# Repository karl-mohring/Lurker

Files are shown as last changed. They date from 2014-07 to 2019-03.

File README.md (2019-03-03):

# Lurker
Wireless sensor network for home environmental monitoring. 

# Installation

## Hardware
### Parts List
1 x Arduino Nano
1 x RF24L01+ Transceiver
1 x DS18B20 Temperature sensor
1 x DHT11 Humidity sensor
1 x BH1750FVI Illuminance sensor
1 x HC-SR501 PIR Motion sensor
2 x 4K7 Ohm resistor (1206 SMD)
2 x 390R Ohm resistor (1206 SMD)
2 x 3mm 2~3V LEDs

Optional - These components are still in development
1 x IR Blaster
1 x IR Receiver
1 x Microphone

### Circuit Board
The Lurker uses a custom PCB to connect the sensors and components together. 

### Casing
## Software

# Usage

# Network Heirarchy

# Other Info

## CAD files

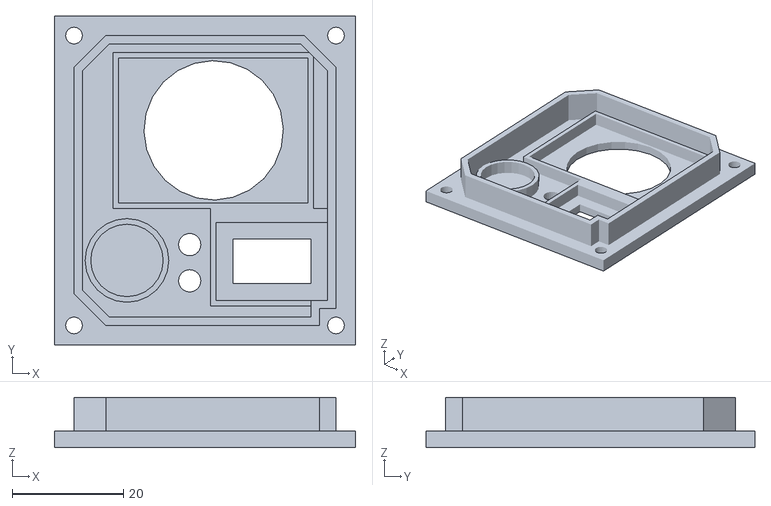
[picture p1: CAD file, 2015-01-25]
CAD/LurkerCase/LurkerLid.stl
54.0 x 59.0 x 9.00

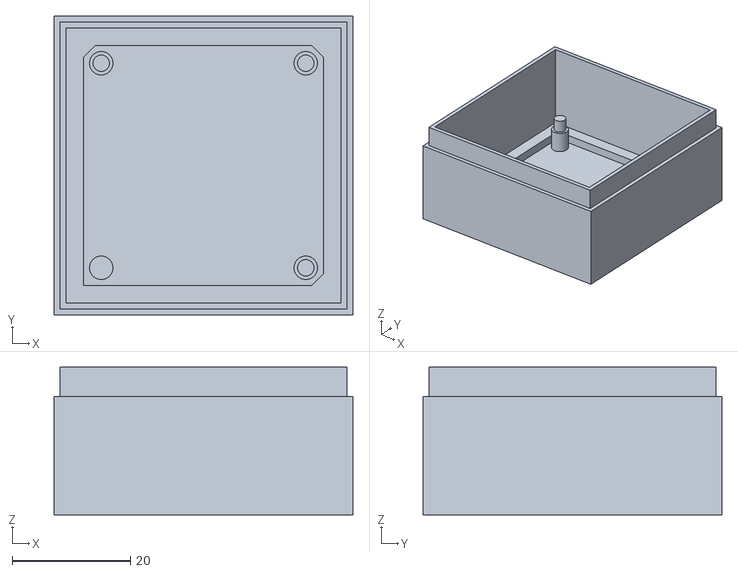
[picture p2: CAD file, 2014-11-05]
CAD/Lurkerv20 Enclosure/Lurkerv20 Baseplate.stl
50.6 x 50.6 x 25.0

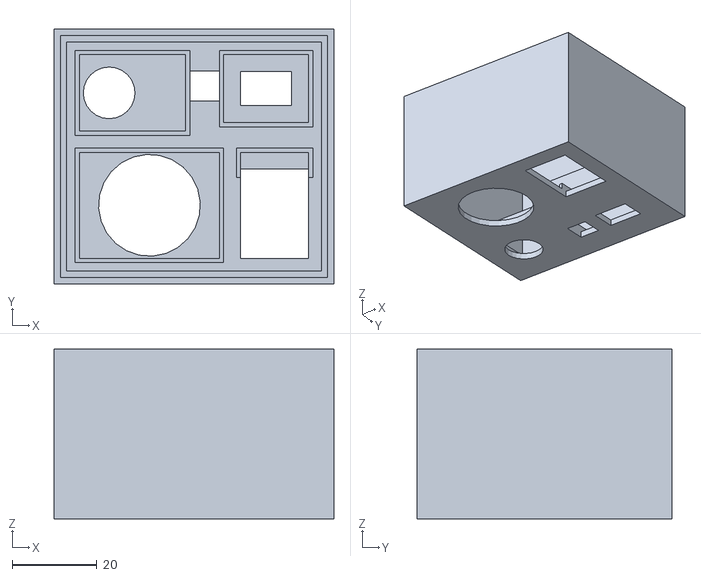
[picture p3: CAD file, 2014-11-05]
CAD/Office Lurker Enclosure/sensor topv1.stl
66.0 x 60.0 x 40.0

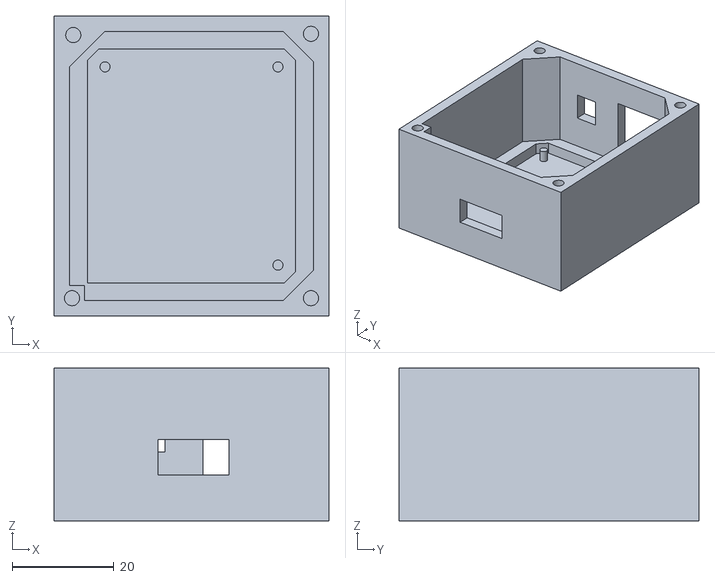
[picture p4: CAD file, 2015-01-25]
CAD/LurkerCase/LurkerCase.stl
54.0 x 59.0 x 30.0

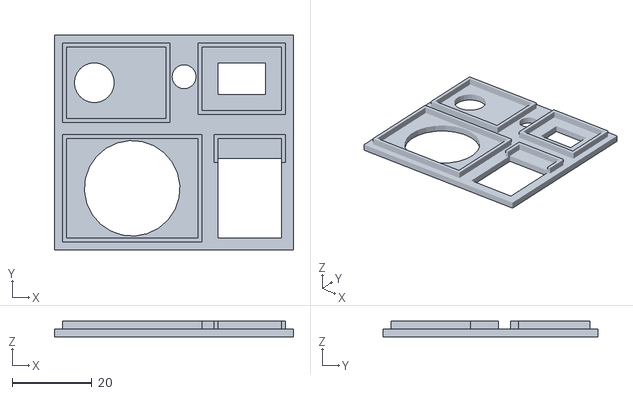
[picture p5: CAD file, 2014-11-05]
CAD/Office Lurker Enclosure/sensor top test_fixed.stl
60.0 x 54.0 x 4.00

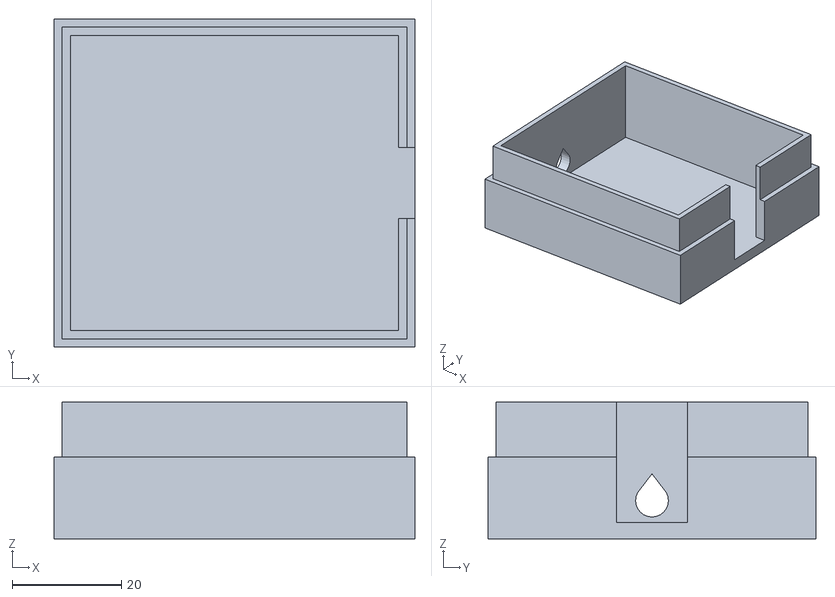
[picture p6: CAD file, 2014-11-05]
CAD/Office Lurker Enclosure/sensor bottom.stl
66.0 x 60.0 x 25.0

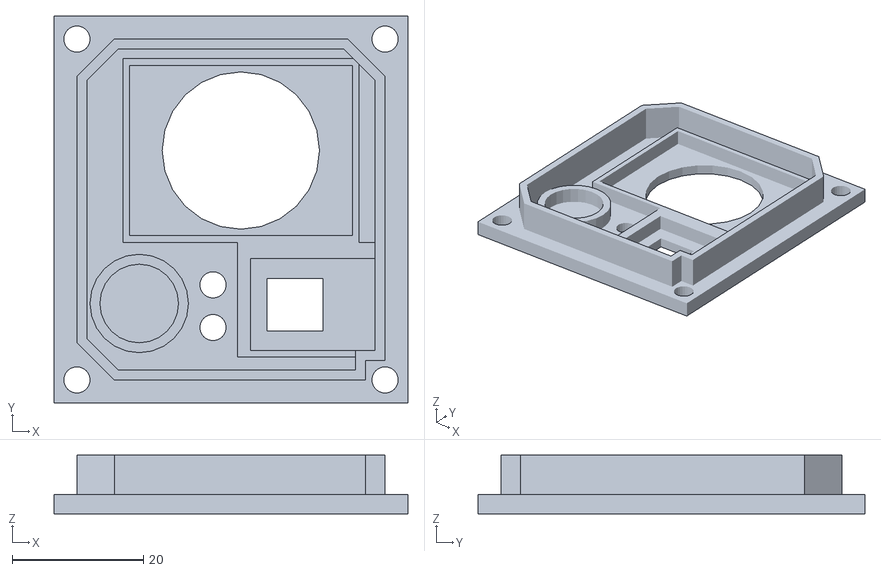
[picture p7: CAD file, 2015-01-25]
CAD/LurkerCase/LurkerLid-v3.stl
54.0 x 59.0 x 9.00

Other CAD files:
CAD/LurkerCase/LurkerCase-v3.stl
CAD/LurkerCase/LurkerCase-v3.skp
CAD/LurkerCase/LurkerCase.skp
CAD/LurkerCase/LurkerLid-v3.skp
CAD/LurkerCase/LurkerLid.skp
CAD/Lurkerv20 Enclosure/Lurkerv20 Baseplate.skp
CAD/Lurkerv20 Enclosure/Lurkerv20 Faceplate.skp
CAD/Office Lurker Enclosure/sensor bottom.skp
CAD/Office Lurker Enclosure/sensor top.skp

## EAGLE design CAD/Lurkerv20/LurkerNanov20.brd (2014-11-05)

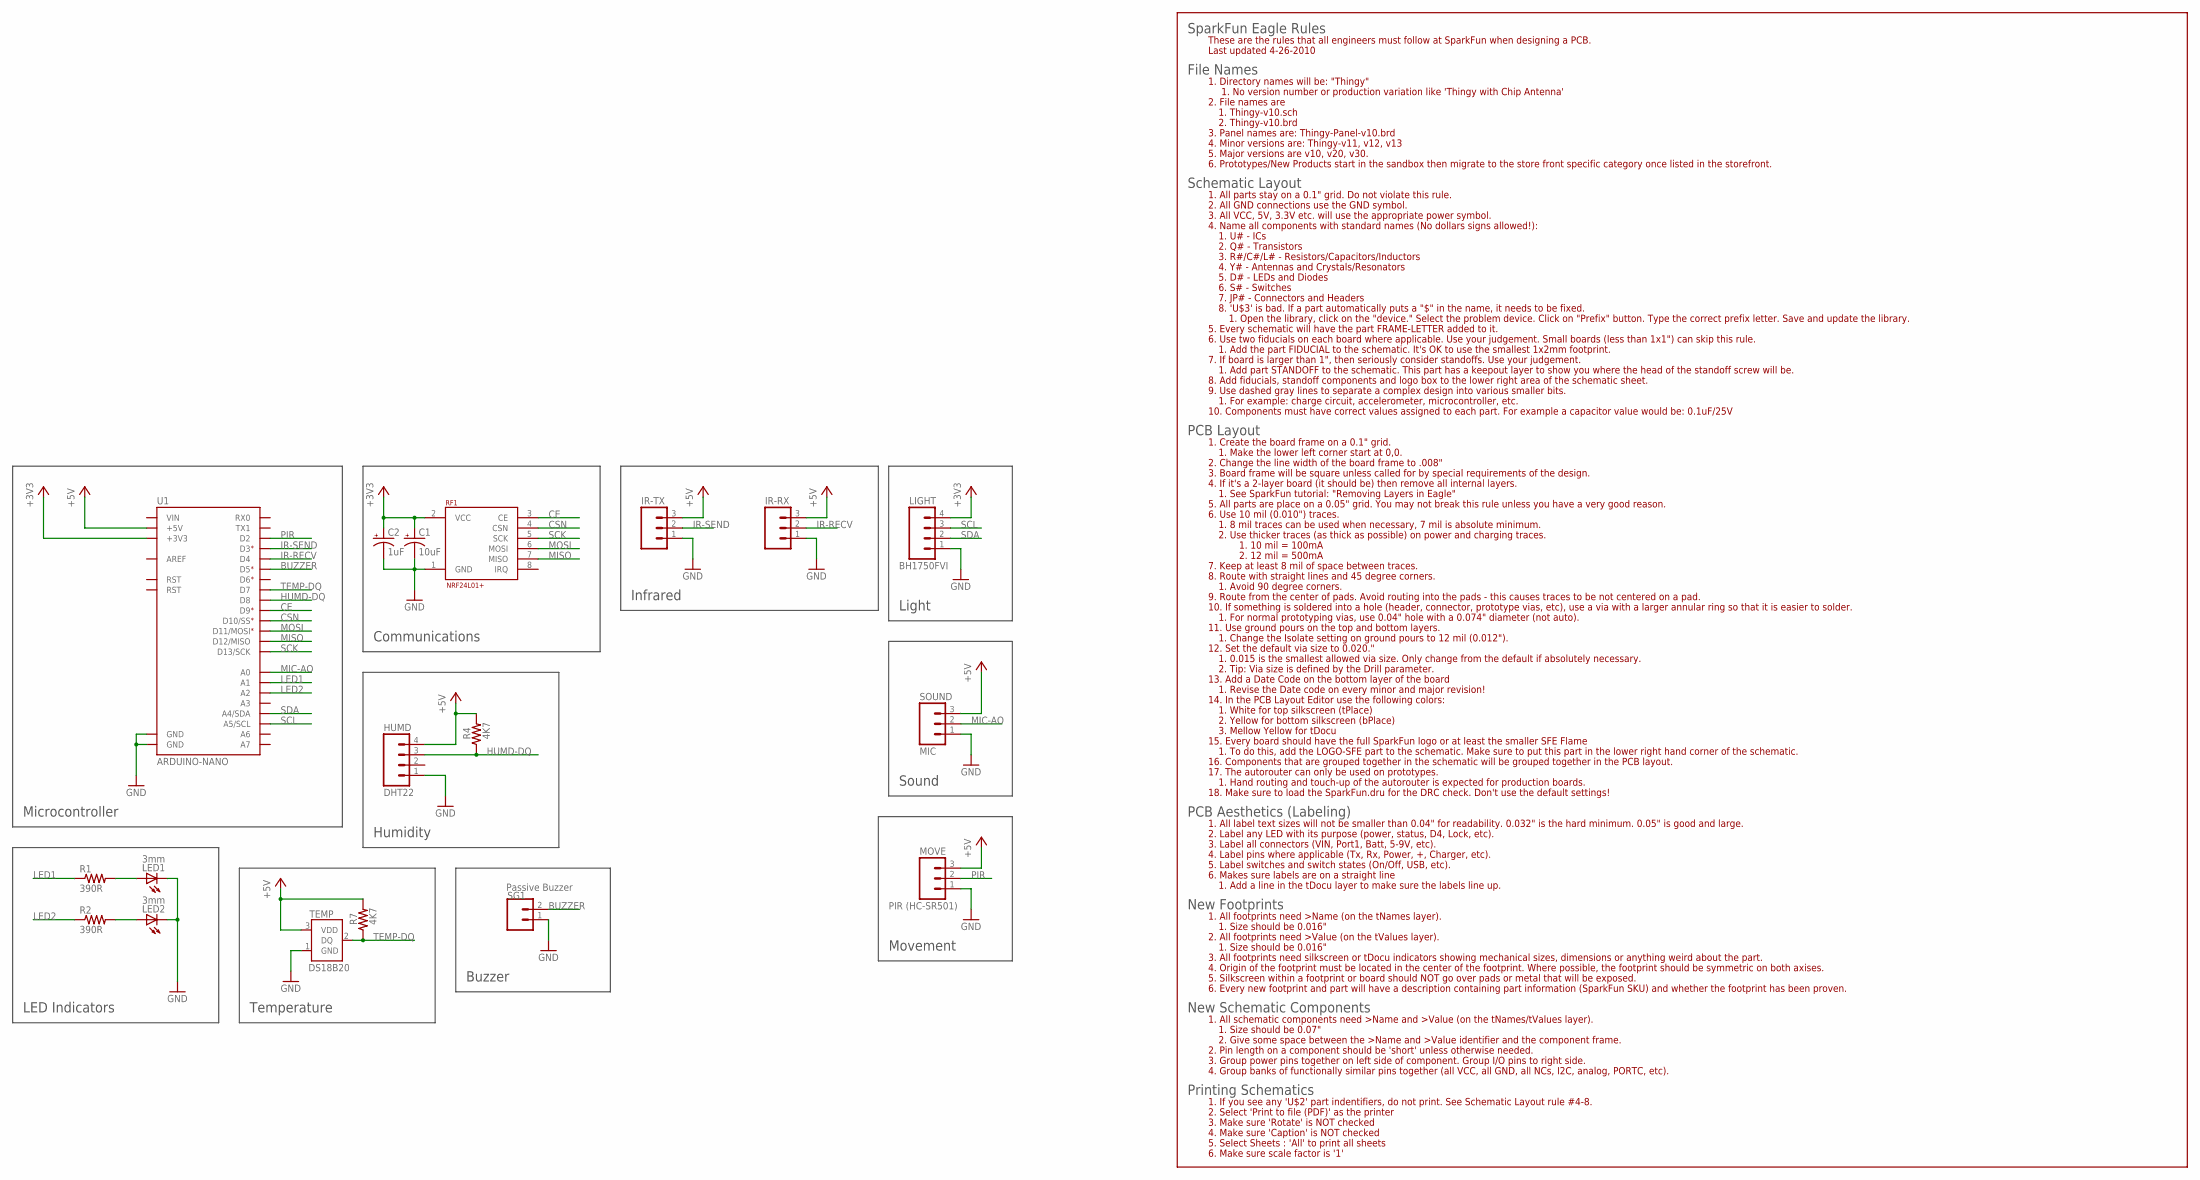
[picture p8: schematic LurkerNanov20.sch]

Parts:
C1: 10uF; EIA3216
C2: 1uF; EIA3216
HUMD: DHT22; 1X04
IR-RX: M03PTH; 1X03
IR-TX: M03PTH; 1X03
LED1, LED2: 3mm; LED3MM
LIGHT: BH1750FVI; 1X04
MOVE: PIR (HC-SR501); 1X03
R1, R2: 390R; 1206
R4, R7: 4K7; 1206
RF1: NRF24L01+; NRF24L01+-HEADER
SG1: Passive Buzzer; 1X02
SOUND: MIC; 1X03
TEMP: DS18B20; TO-92-AMMO
U1: ARDUINO-NANO; NANO-SHIELD

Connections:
+3V3: C1.A (+), C2.A (+), LIGHT.4, RF1.2 (VCC), U1.3V3 (+3V3)
+5V: HUMD.4, IR-RX.3, IR-TX.3, MOVE.3, R4.2, R7.2, SOUND.3, TEMP.3 (VDD), U1.5V (+5V)
BUZZER: SG1.2, U1.D5
CE: RF1.3 (CE), U1.D9
CSN: RF1.4 (CSN), U1.D10 (D10/SS)
GND: C1.C (-), C2.C (-), HUMD.1, IR-RX.1, IR-TX.1, LED1.K (C), LED2.K (C), LIGHT.1, MOVE.1, RF1.1 (GND), SG1.1, SOUND.1, TEMP.1 (GND), U1.GND@0 (GND), U1.GND@1 (GND)
HUMD-DQ: HUMD.3, R4.1, U1.D8
IR-RECV: IR-RX.2, U1.D4
IR-SEND: IR-TX.2, U1.D3
LED1: R1.1, U1.A1
LED2: R2.1, U1.A2
MIC-AO: SOUND.2, U1.A0
MISO: RF1.7 (MISO), U1.D12 (D12/MISO)
MOSI: RF1.6 (MOSI), U1.D11 (D11/MOSI)
unnamed: LED1.A, R1.2
unnamed: LED2.A, R2.2
PIR: MOVE.2, U1.D2
SCK: RF1.5 (SCK), U1.D13 (D13/SCK)
SCL: LIGHT.3, U1.A5 (A5/SCL)
SDA: LIGHT.2, U1.A4 (A4/SDA)
TEMP-DQ: R7.1, TEMP.2 (DQ), U1.D7
VIN: U1.VIN

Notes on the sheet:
Microcontroller
Temperature
Communications
Infrared
Buzzer
LED Indicators
Sound
Light
Movement
Humidity

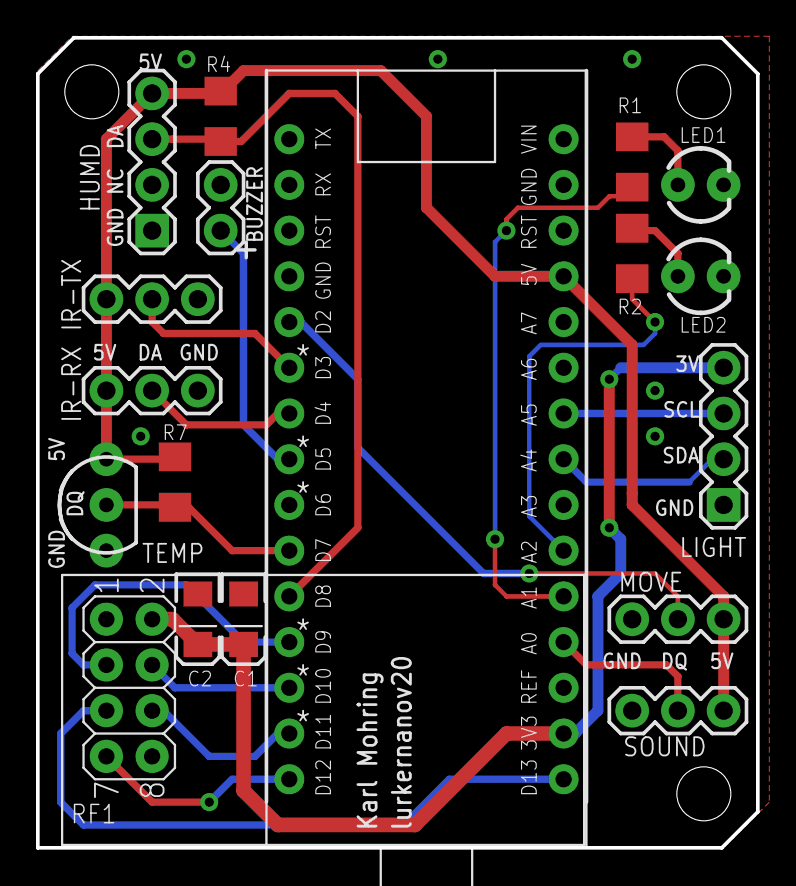
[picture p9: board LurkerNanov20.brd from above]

Board: 2 copper layers, 40.0 x 45.0 mm, 18 parts (0 on the bottom side), 21 nets.

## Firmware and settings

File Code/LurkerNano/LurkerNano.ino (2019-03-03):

#include <dht.h>
#include <CommandHandler.h>
#include <RF24_config.h>
#include <RF24.h>
#include <nRF24L01.h>
#include <Logging.h>
#include <SPI.h>
#include <StraightBuffer.h>
#include <SimpleTimer.h>
#include <Wire.h>
#include <OneWire.h>
#include <DallasTemperature.h>
#include <BH1750FVI.h>
#include <JsonGenerator.h>
#include "avr/wdt.h"
#include "avr/pgmspace.h"
#include "lurker_settings.h"

using namespace ArduinoJson::Generator;

const float LURKER_VERSION = 0.9;

//////////////////////////////////////////////////////////////////////////
// Lurker Nano
//
// The lurker is a small and inexpensive WSN node for home climate
// monitoring.
//
// Sensors:
//	- Temperature
//	- Humidity
//	- Illuminance
//	- Motion
//	- IR Receiver (not implemented)
//
// Actuators:
//	- Buzzer (active)
//	- IR Blaster
//	- 2 LEDs
//
//////////////////////////////////////////////////////////////////////////
// Hardware Config

// Temperature
OneWire oneWire(TEMPERATURE_PIN);
DallasTemperature tempSensor(&oneWire);

// Humidity
dht humiditySensor;

// Illuminance
BH1750FVI lightSensor;

// Motion
bool motionDetected;
long timeOfLastMotion;

// Buzzer
RF24 radio(CE_PIN, CSN_PIN);

// Lights
int leds[] = { LED0, LED1, LED_BUILTIN };


//////////////////////////////////////////////////////////////////////////
// Soft Config

// Sample Timer
SimpleTimer timer;
int joinTimerID;
int networkTimeoutTimerID;
int printDataTimerID;
int motionTimerId;

// Communication
bool connectedToNetwork = false;

String received = "";
bool recording = false;

// Radio Buffer
byte _readBuffer[BUFFER_LENGTH];
byte _writeBuffer[BUFFER_LENGTH];
StraightBuffer readBuffer(_readBuffer, BUFFER_LENGTH);
StraightBuffer writeBuffer(_writeBuffer, BUFFER_LENGTH);

// Coordinator - Routing table
int routingTable[MAX_NETWORK_SIZE];

// Sensor data object
JsonObject<8> sensorData;
JsonObject<5> remoteData;

// Command handlers
char _commandCache[BUFFER_LENGTH];
CommandHandler commandHandler(_commandCache, BUFFER_LENGTH);

// Logger 
char p_buffer[80];
#define P(str) (strcpy_P(p_buffer, PSTR(str)), p_buffer)


//////////////////////////////////////////////////////////////////////////
// Main Functions
//////////////////////////////////////////////////////////////////////////

/**
* Initial script - Run once
*/
void setup()
{
	// Starting up the Lurker - say hello :D
	Log.Init(LOGGER_LEVEL, SERIAL_BAUD);
	Log.Info(P("Lurker starting - %s"), unitID.c_str());

	// Start all the things
	startSensors();
	initialiseBuzzer();
	initialiseRadio();
	initialiseLights();
	startCommandHandler();
}

/**
* Main Loop
*/
void loop(){
	timer.run();

	checkSerial();
	//checkRadio();
}


//////////////////////////////////////////////////////////////////////////
// Communication - Wired

// Periodic function - Transmit sensor data over serial
/**
* Send sensor data to the connected device
* Sensor data is structured in JSON format
*/
void printSensorData(){
	readSensors();

	Serial.print(PACKET_START);
	Serial.print(sensorData);
	Serial.println(PACKET_END);
}

/**
* Check serial for incoming packets
*/
void checkSerial(){
	while (Serial.available()){
		char inChar = Serial.read();
		commandHandler.readIn(inChar);
	}
}

/**
* Bind commands for the serial and rf24 interface
*/
void startCommandHandler(){
	Log.Debug(P("Adding commands"));

	commandHandler.setTerminator(PACKET_END);
	Log.Info(P("Terminate characters with a '%c' character"), PACKET_END);
	commandHandler.setDefaultHandler(commandNotRecognised);

	// User functions
	commandHandler.addCommand(BUZZER_ON_CODE, buzzerOn);
	Log.Info(P("%c - Buzzer ON"), BUZZER_ON_CODE);

	commandHandler.addCommand(BUZZER_OFF_CODE, buzzerOff);
	Log.Info(P("%c - Buzzer OFF"), BUZZER_OFF_CODE);

	commandHandler.addCommand(SENSOR_READ_REQUEST, printSensorData);
	Log.Info(P("%c - Read sensors"), SENSOR_READ_REQUEST);

	// Internal functions
	if (UNIT_NUMBER == COORDINATOR){
		commandHandler.addCommand(NETWORK_JOIN_REQUEST, addNodeToNetwork);
		commandHandler.addCommand(DATA_TRANSMIT_RESPONSE, resetRemoteDataStorage);
		commandHandler.addCommand(UNIT_ID_CODE, readRemoteUnitNumber);
		commandHandler.addCommand(TEMPERATURE_CODE, readRemoteTemperature);
		commandHandler.addCommand(HUMIDITY_CODE, readRemoteHumidity);
		commandHandler.addCommand(ILLUMINANCE_CODE, readRemoteIlluminance);
		commandHandler.addCommand(MOTION_CODE, readRemoteMotion);
		commandHandler.addCommand(DATA_PACKET_FINISHED, processRemoteDataPacket);
	}

	else{
		commandHandler.addCommand(NETWORK_JOIN_CONFIRM, processNetworkJoin);
		commandHandler.addCommand(DATA_TRANSMIT_REQUEST, transmitDataPacket);
	}
}

/**
* Callback for an unknown command
*/
void commandNotRecognised(const char command){
	Log.Error(P("Warning - Unknown command [%c]"), char(command));
}


//////////////////////////////////////////////////////////////////////////
// Communication - Wireless

/**
* Initialise the RF24 radio
*/
void initialiseRadio(){
	// Set up the options for the transceiver
	radio.begin();
	radio.setDataRate(RF24_1MBPS);
	radio.setPALevel(RF24_PA_MAX);
	radio.setRetries(15, 15);
	connectedToNetwork = false;

	// Open communication channels
	radio.openWritingPipe(BASE_PIPE);

	radio.openReadingPipe(1, UNIT_PIPE);
	Log.Debug(P("Reading pipe: %l"), UNIT_PIPE);

	radio.openReadingPipe(2, BROADCAST_PIPE);
	Log.Debug(P("Reading pipe: %l"), BROADCAST_PIPE);

	// Set up network joining
	if (UNIT_NUMBER != COORDINATOR){
		timer.setInterval(NETWORK_JOIN_INTERVAL, joinNetwork);
	}

	radio.startListening();

	Log.Debug(P("Radio started"));
}

/**
* Check the radio for any incoming packets.
*/
void checkRadio(){
	if (radio.available()){

		Log.Info(P("Packet received"));
		readRadioPacket();

		// Get rid of any unfinished serial commands in the buffer
		commandHandler.clearCache();

		// Read in the packet, one byte at a time
		char command = readBuffer.read();
		while (readBuffer.available() && command != 0){
			command = readBuffer.read();
			commandHandler.readIn(command);

			Log.Debug(P("Command: [%i]"), command);
		}
	}
}

/**
* Read the incoming radio packet into the read buffer
*/
void readRadioPacket(){
	radio.read(readBuffer.getBufferAddress(), BUFFER_LENGTH);
	readBuffer.setWritePosition(BUFFER_LENGTH);
}

/**
* Transmit a character to the specified node
*/
void transmitChar(char message){
	radio.stopListening();
	radio.write(&message, 1);
	radio.startListening();

	Log.Verbose(P("Sending: %c"), message);
}


//////////////////////////////////////////////////////////////////////////
// Coordinator Functions

/**
* Change a units' status to active in the routing table
*/
void addNodeToNetwork(){
	char unitNum = commandHandler.next();

	// Units are numbered sequentially, make sure the number is not too high
	if (unitNum <= MAX_NETWORK_SIZE){
		routingTable[unitNum] = timer.setTimeout(NODE_TIMEOUT, cleanRoutingTable);
		Log.Info(P("Unit %i joined the network"), unitNum);
	}
}

/**
* Go through the routing table and disable units that have timed out
*/
void cleanRoutingTable(){
	for (int i = 0; i < MAX_NETWORK_SIZE; i++){

		// Active units have a timer ID higher than -1.
		if (routingTable[i] >= 0){

			// Clear any units from the routing table that are non-responsive
			if (!timer.isEnabled(routingTable[i])){
				Log.Info(P("Unit %i timed out"), i);
				routingTable[i] = -1;
			}
		}
	}
}

/**
* Reset the remote data values to prepare for a new packet
*/
void resetRemoteDataStorage(){
	remoteData[ID] = "None";
	remoteData[TEMPERATURE] = 0.0;
	remoteData[HUMIDITY] = 0;
	remoteData[ILLUMINANCE] = 0;
	remoteData[MOTION] = false;
}

/**
* Read in the unit number from the received packet
*/
void readRemoteUnitNumber(){
	char arg = commandHandler.next();
	int unitNumber = byte(arg);

	if (unitNumber < MAX_NETWORK_SIZE){
		remoteData[ID] = unitNumber;

		// Reset the timeout of the sender
		resetTimeout(unitNumber);
	}
}

/**
* Read in the temperature from the received packet
*/
void readRemoteTemperature(){
	char argHigh = commandHandler.next();
	char argLow = commandHandler.next();
	float temperature = word(argHigh, argLow);
	temperature /= 100.0;

	remoteData[TEMPERATURE] = temperature;
}

/**
* Read in the humidity from the received packet
*/
void readRemoteHumidity(){
	char argHigh = commandHandler.next();
	char argLow = commandHandler.next();
	float humidity = word(argHigh, argLow);
	humidity /= 100.0;

	remoteData[HUMIDITY] = humidity;
}

/**
* Read in the illuminance from the received packet
*/
void readRemoteIlluminance(){
	char argHigh = commandHandler.next();
	char argLow = commandHandler.next();
	int illuminance = word(argHigh, argLow);

	remoteData[ILLUMINANCE] = illuminance;
}

/**
* Read in the motion detector status from the received packet
*/
void readRemoteMotion(){
	bool motion = commandHandler.next();

	remoteData[MOTION] = motion;
}

/**
* Print the received data values to the buffer
*/
void processRemoteDataPacket(){
	Serial.print(PACKET_START);
	Serial.print(remoteData);
	Serial.println(PACKET_END);
}

/**
* Reset the timeout of a node
*/
void resetTimeout(int unitNumber){
	timer.restartTimer(routingTable[unitNumber]);
}

/**
* Callback function
* Request a data packet from a remote node.
*
* Requests are made sequentially through the routing table.
* If a node is not active, nothing happens, rather than skipping ahead to an active node.
* It's a lot less spammy that way...
*
* Also, the coordinator will be in its own routing table, but the coordinator has no methods
* to join its own network. It should be fine...
* The break in requests gives the coordinator a chance to upload its own data.
*/
void requestNodeData(){
	static int index = 0;

	// Get data from the next connected node
	if (routingTable[index] >= 0){
		Log.Info(P("Requesting data from Unit %i"), index);
		sendPacketRequest(index);
	}

	// Increment node number or loop back to start
	if (index < MAX_NETWORK_SIZE){
		index++;
	}
	else{
		index = 0;
	}
}

/**
* Send a data packet request to the specified node
* @param unitNumber Unit number of the destination node
*/
void sendPacketRequest(int unitNumber){
	writeBuffer.reset();

	writeBuffer.write(DATA_TRANSMIT_REQUEST);
	writeBuffer.write(PACKET_END);

	radio.openWritingPipe(BASE_PIPE + unitNumber);
	transmitWriteBuffer();
}

//////////////////////////////////////////////////////////////////////////
// Node Functions

/**
* Callback function
* Join the RF24 network if not already connected.
* The network coordinator holds the networking table and does not need to join.
*/
void joinNetwork(){
	if (!connectedToNetwork && UNIT_NUMBER != COORDINATOR){
		transmitJoinRequest();
	}
}

/**
* Callback function
* The node's network connection has timed out (no requests from coordinator)
* Reset the node's RF24 network membership
*/
void resetNodeNetworkConnection(){
	Log.Info(P("Timed out from network"));
	connectedToNetwork = false;
}

/**
* Send a network request to the network coordinator
*/
void transmitJoinRequest(){
	writeBuffer.reset();

	writeBuffer.write(NETWORK_JOIN_REQUEST);
	writeBuffer.write(UNIT_NUMBER);

	writeBuffer.write(PACKET_END);

	transmitWriteBuffer();
	Log.Debug(P("Attempting network join"));
}

/**
* Transmit the collected sensor data to the network coordinator
*/
void transmitDataPacket(){
	// Senpai noticed us! Restart the timeout
	timer.restartTimer(networkTimeoutTimerID);
	Log.Info(P("Data request received"));

	prepareDataPacket();
	transmitWriteBuffer();
}

/**
* Transmit the contents of the write buffer using the RF24 network
*/
void transmitWriteBuffer(){
	radio.stopListening();
	radio.write(writeBuffer.getBufferAddress(), writeBuffer.getWritePosition());
	radio.startListening();
}

/**
* Load the sensor data to the write buffer
*/
void prepareDataPacket(){
	writeBuffer.reset();
	writeBuffer.write(DATA_TRANSMIT_RESPONSE);

	writeBuffer.write(UNIT_ID_CODE);
	writeBuffer.write(UNIT_NUMBER);

	writeBuffer.write(TEMPERATURE_CODE);
	writeBuffer.writeInt(int(int(sensorData[TEMPERATURE]) * 100));

	writeBuffer.write(HUMIDITY_CODE);
	writeBuffer.write(int(sensorData[HUMIDITY]));

	writeBuffer.write(ILLUMINANCE_CODE);
	writeBuffer.writeInt(int(sensorData[ILLUMINANCE]));

	writeBuffer.write(MOTION_CODE);
	writeBuffer.write(int(sensorData[MOTION]));

	writeBuffer.write(DATA_PACKET_FINISHED);

	writeBuffer.write(PACKET_END);
}

/**
* Confirm the RF24 network has been joined so we can stop spamming the coordinator
*/
void processNetworkJoin(){
	connectedToNetwork = true;
	networkTimeoutTimerID = timer.setTimeout(NODE_TIMEOUT, resetNodeNetworkConnection);

	Log.Info(P("Joined network"));
}


//////////////////////////////////////////////////////////////////////////
// Sensors

/**
* Initialise all attached sensors
*/
void startSensors(){
	sensorData[ID] = unitID.c_str();
	sensorData["version"] = LURKER_VERSION;

	Log.Debug(P("Starting sensors..."));

	startTemperature();
	startHumidity();
	startIlluminance();
	startMotion();

	// Set up periodic sensor reads
	printDataTimerID = timer.setInterval(SAMPLE_INTERVAL, printSensorData);
}

/**
* Read all sensors
*/
void readSensors(){
	sensorData[TEMPERATURE] = readTemperature();
	sensorData[HUMIDITY] = readHumidity();
	sensorData[ILLUMINANCE] = readIlluminance();
	sensorData[MOTION] = motionDetected;

	flashSensorReadLight();
}

/**
* Start the temperature sensor
*/
void startTemperature(){
	tempSensor.begin();
	Log.Debug(P("Temperature started..."));
}

/**
* Take a temperature reading
*
* Returns:
*	Temperature reading in degrees Celsius
*/
float readTemperature(){
	tempSensor.requestTemperatures();
	return tempSensor.getTempCByIndex(0);;
}

/**
* Start the humidity sensor
*/
void startHumidity(){
	Log.Debug(P("Humidity started..."));
}

/**
* Take a humidity reading.
* May take up to 2 seconds with the DHT11 sensor
*
* Returns:
*	Relative humidity as a floating percentage
*/
float readHumidity(){
	float humidity = 0;
	int status = humiditySensor.read11(HUMIDITY_PIN);

	// Grab the data if read was successful
	if (status == DHTLIB_OK){
		humidity = humiditySensor.humidity;
	}
	else{
		Log.Error(P("Error reading humidity sensor. Error [%i]"), status);
	}

	return humidity;
}

/**
* Initialise the light sensor
*/
void startIlluminance(){
	lightSensor.begin();
	lightSensor.SetAddress(Device_Address_L);
	lightSensor.SetMode(Continuous_H_resolution_Mode);

	Log.Debug(P("Illuminance started"));
}

/**
* Take an illuminance reading
*
* Returns:
*	Illuminance in lux
*/
long readIlluminance(){
	return lightSensor.GetLightIntensity();
}

/**
* Initialise the PIR motion sensor
*/
void startMotion(){
	pinMode(MOTION_PIN, INPUT);
	motionDetected = false;

	// Enter sensor cooldown for calibration
	enterMotionCooldown();
	Log.Debug(P("Motion started"));
}

/**
* Check the PIR sensor for detected movement
* The sensor will output HIGH when motion is detected.
* Detections will hold the detection status HIGH until the cool-down has lapsed (default: 60s)
*
* Returns:
*	True if motion has been detected recently
*/
void readMotion(){
	// Check the sensor
	if (digitalRead(MOTION_PIN) == MOTION_DETECTED){
		motionDetected = true;
		flashMotionLight();
		Log.Debug(P("Motion detected"));

		enterMotionCooldown();
	}

	else{
		// No alarm; is fine
		motionDetected = false;
	}
}

/**
* Start the motion sensor cooldown to avoid multiple detections per event
* Cooldown is entered after every detection event, and for calibration.
*/
void enterMotionCooldown(){
	timer.deleteTimer(motionTimerId);
	motionTimerId = -1;

	timer.setTimeout(MOTION_COOLOFF, endMotionCooldown);
}

/**
* Callback function - Start monitoring the motion sensor again after a cooldown
*/
void endMotionCooldown(){
	motionTimerId = timer.setInterval(MOTION_CHECK_INTERVAL, readMotion);
}


//////////////////////////////////////////////////////////////////////////
// Buzzer

/**
* Initialise the passive buzzer
*/
void initialiseBuzzer(){
	pinMode(BUZZER_PIN, OUTPUT);
	buzzerOff();
	Log.Debug(P("Buzzer started..."));
}

/**
* Turn on the buzzer
*/
void buzzerOn(){
	digitalWrite(BUZZER_PIN, HIGH);
	Log.Debug(P("Buzzer On"));
}

/**
* Turn the buzzer off
*/
void buzzerOff(){
	digitalWrite(BUZZER_PIN, LOW);
	Log.Debug(P("Buzzer Off"));
}


//////////////////////////////////////////////////////////////////////////
// LEDs

/**
* Initialise the LED indicator lights
* Their default state is OFF
*/
void initialiseLights(){
	for (int i = 0; i < NUM_LEDS; i++){
		pinMode(leds[i], OUTPUT);
		switchLight(i, OFF);
	}
}

/**
* Switch the LED indicator light on or off.
* LEDs are directly supplied by the MCU pins
*
* Arguments:
*	lightPin - Pin location of the LED to be switched
*	state - boolean state of the LED, high for ON.
*/
void switchLight(int ledNum, bool state){
	if (ledNum < sizeof(leds)){
		digitalWrite(leds[ledNum], state);
	}

	Log.Debug(P("LED %i on pin %i switched to %T"), ledNum, leds[ledNum], state);
}

/**
* Briefly flash the motion sensor indicator
*/
void flashMotionLight(){
	switchLight(MOTION_LED, ON);

	timer.setTimeout(FLASH_TIME, endMotionLightFlash);

}

/**
* Callback for the flashMotionLight timer
* Turn the motion light off after the timer expires
*/
void endMotionLightFlash(){
	switchLight(MOTION_LED, OFF);
}

/**
* Flash the sensor read indicator
*/
void flashSensorReadLight(){
	switchLight(SENSOR_READ_LED, ON);

	timer.setTimeout(FLASH_TIME, endSensorReadFlash);
}

/**
* Callback for the flashSensorReadLight function
* Turns the read light off after the timer elapses
*/
void endSensorReadFlash(){
	switchLight(SENSOR_READ_LED, OFF);
}

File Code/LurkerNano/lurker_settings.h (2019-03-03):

#include <Arduino.h>
#include "avr/pgmspace.h"

//////////////////////////////////////////////////////////////////////////
// Network Config

const byte COORDINATOR = 0;
const long NODE_TIMEOUT = 120000;	// Period before the routing table is reset and nodes need to rejoin
const byte MAX_NETWORK_SIZE = 5;

//////////////////////////////////////////////////////////////////////////
// Unit-Specific Config
const byte UNIT_NUMBER = 0;
String unitClass = "lurker";
String unitID = unitClass + UNIT_NUMBER;

//////////////////////////////////////////////////////////////////////////

const long SAMPLE_INTERVAL = 20000;	// Sample interval in ms

// DS18B20 Temperature Probe
const byte TEMPERATURE_PIN = 7;

// DHT11 Humidity Sensor
const byte HUMIDITY_PIN = 8;

// PIR Motion detector
const byte MOTION_PIN = 2;
const int MOTION_INITIALISATION_TIME = 2000; // Initialisation period in ms
const long MOTION_COOLOFF = 5000;	//Cool off period in ms
const int MOTION_CHECK_INTERVAL = 100;	// Period between motion detector checks in ms
const byte MOTION_DETECTED = HIGH;

// Passive buzzer
const byte BUZZER_PIN = 5;

// LEDs
const byte LED0 = A1;
const byte LED1 = A2;
const byte ON = HIGH;
const byte OFF = LOW;
const byte MOTION_LED = 1;
const byte SENSOR_READ_LED = 0;
const long FLASH_TIME = 500;
const byte NUM_LEDS = 3;

// Radio
const byte CE_PIN = 9;
const byte CSN_PIN = 10;

const long SERIAL_BAUD = 115200;
const long NETWORK_JOIN_INTERVAL = 60000; // Time between network join attempts in ms

// Logging
const int LOGGER_LEVEL = LOG_LEVEL_INFOS;


// Communication Pipes
PROGMEM const long BROADCAST_PIPE = 0x90909090FFLL;
PROGMEM const long BASE_PIPE = 0x9090909000LL;
PROGMEM const long UNIT_PIPE = BASE_PIPE + UNIT_NUMBER;

// Comm Tags
const char PACKET_START = '#';
const char PACKET_END = '$';
const char DELIMITER = ' ';

const char NETWORK_JOIN_REQUEST = 'j';
const char NETWORK_JOIN_CONFIRM = 'J';
const char NETWORK_CONNECTION_RESET = 'R';
const char SENSOR_READ_REQUEST = 'r';
const char DATA_TRANSMIT_REQUEST = 'D';
const char DATA_TRANSMIT_RESPONSE = 'd';
const char DATA_PACKET_FINISHED = 'F';

const char UNIT_ID_CODE = 'Z';
const char TEMPERATURE_CODE = 'T';
const char HUMIDITY_CODE = 'H';
const char ILLUMINANCE_CODE = 'I';
const char MOTION_CODE = 'M';

const char BUZZER_ON_CODE = 'B';
const char BUZZER_OFF_CODE = 'b';

const char LIGHT_ON_CODE = 'L';
const char LIGHT_OFF_CODE = 'l';

const char ID[] = "id";
const char TEMPERATURE[] = "temperature";
const char HUMIDITY[] = "humidity";
const char MOTION[] = "motion";
const char ILLUMINANCE[] = "illuminance";

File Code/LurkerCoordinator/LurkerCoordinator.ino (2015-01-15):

#include <JsonParser.h>
#include <JsonGenerator.h>
#include <IRremote.h>
#include <SPI.h>
#include <Wire.h>
#include <DallasTemperature.h>
#include <RF24_config.h>
#include <RF24.h>
#include <nRF24L01.h>
#include <OneWire.h>
#include <BH1750FVI.h>
#include <DHT.h>
#include <SimpleTimer.h>

using namespace ArduinoJson::Generator;


//////////////////////////////////////////////////////////////////////////
// Unit-Specific Config
const int UNIT_ID = 0;
String unit_class = String("lurker");
String unit_identifer = unit_class + UNIT_ID;


//////////////////////////////////////////////////////////////////////////
// Hardware Config

// Temperature
#define TEMPERATURE_PIN 7
OneWire oneWire(TEMPERATURE_PIN);
DallasTemperature tempSensor(&oneWire);
float temperature;

// Humidity
#define HUMIDITY_PIN 8
#define DHT_TYPE DHT11
DHT humiditySensor(HUMIDITY_PIN, DHT_TYPE);
float humidity;

// Light
BH1750FVI lightSensor;
long illuminance;

// Sound
#define MIC_ANALOG_PIN A0
#define SOUND_OVER_THRESHOLD LOW
#define NOISE_COOLOFF 10	// Cool-off between noise alarms in seconds
int noiseLevel;

// Movement
#define MOTION_PIN 2
#define MOTION_COOLOFF 10 // Cool-off between motion alarms in seconds
#define MOTION_CALIBRATION_TIME 2 //Calibration time in seconds
#define MOVEMENT_DETECTED HIGH
bool motionDetected;


//////////////////////////////////////////////////////////////////////////
// Software Config

SimpleTimer timer;
#define SAMPLE_PERIOD  20000	// Sample period in ms


//////////////////////////////////////////////////////////////////////////
// Main Functions
//////////////////////////////////////////////////////////////////////////

/**
* Initialization
*/
void setup(){
	Serial.begin(57600);
	printOpeningMessage();
	
	initialiseRadio();
	initialiseSensors();
	
	startEnumeration();
}


/**
* Main Loop
*/
void loop(){
	checkSerial();
	checkRadio();
	checkSensors();
}

//////////////////////////////////////////////////////////////////////////
//////////////////////////////////////////////////////////////////////////
// Buffers & Misc

/**
* Insert a character into the send buffer
*/
void toSendBuffer(char c){
	// Only insert character if there is room left in the buffer
	if (sendBufferPutter < SEND_BUFFER_SIZE){
		sendBuffer[sendBufferPutter] = c;
		sendBufferPutter++;
	}
}


/**
* Initialise the send buffer
*/
void resetSendBuffer(){
	sendBufferPutter = 0;
}


/**
* Get the next character from the receive buffer
*/
char fromReceiveBuffer(){
	char c = receiveBuffer[receiveBufferGetter];
	
	if (receiveBufferGetter < RECEIVE_BUFFER_SIZE){
		receiveBufferGetter++;
	}
	
	return c;
}


/**
* Initialize the receive buffer by resetting the getter position
*/
void resetReceiveBuffer(){
	receiveBufferGetter = 0;
}


/**
* Add a new unit ID to the routing table
* No new entries will be added if the table is already full
*/
void addRoutingTableEntry(char unitID){
	// Only insert character if there is room left in the buffer
	if (routingTablePutter < MAX_NETWORK_DEVICES){
		routingTable[routingTablePutter] = unitID;
		routingTablePutter++;
	}
}


/**
* Flush all routing table entries and ready the table for new entries
*/
void resetRoutingTable(){
	routingTablePutter = 0;
	
	for(int i = 0; i < MAX_NETWORK_DEVICES; i++){
		routingTable[i] = 0;
	}
}


/**
* Return the address of a unit ID in the routing table
* @return Routing table index of the specified unit ID
* @return -1 if the unit ID is not found
*/
int findRoutingEntry(char unitID){
	int entryIndex = -1;
	
	for(int i = 0; i < MAX_NETWORK_DEVICES; i++){
		if (routingTable[i] == unitID){
			entryIndex = i;
			break;
		}
	}
	
	return entryIndex;
}


/**
* Convert a floating point decimal number into an int
* The decimal is shifted prior to conversion to preserve precision, but reduce range.
* e.g. floatToInt(12.34, 2) = 1234
*
* @return decimal-shifted integer
* @param num Float number to convert
* @param decimalShift Number of decimal shifts (1-4)
*/
int floatToInt(float num, int decimalShift){
	long decimalMultiplier = 1;
	
	if(decimalShift > 0 && decimalShift < 5){
		decimalMultiplier = pow(10, decimalShift);
	}
	
	return (int)(num*decimalMultiplier);
}


//////////////////////////////////////////////////////////////////////////
// Communications - RF24

/**
* Start the RF24 radio.
* Initiliases listening pipes and allows incoming messages
*/
void initialiseRadio(){
	radio.begin();
	radio.setRetries(15, 5);
	radio.setPALevel(RF24_PA_MAX);
	
	// Start listening on unit-specific pipe
	radio.openReadingPipe(1, unitPipe);
	
	// Listen on broadcast pipe if not the base-station (UNIT 0)
	if (UNIT_ID != 0){
		radio.openReadingPipe(2, BROADCAST_PIPE);
	}
	
	radio.startListening();
}


/**
* Notify any listening network devices that enumeration has begun.
*/
void startEnumeration(){
	// Flush the routing table
	resetRoutingTable();
	
	// Start the renumeration phase; notify the nodes on the broadcast channel
	radio.stopListening();
	radio.openWritingPipe(BROADCAST_PIPE);
	resetSendBuffer();
	toSendBuffer(NETWORK_ENUMERATION_NOTIFIER);
	for(int i = 0; i < 3; i++){
		radio.write(sendBuffer, sendBufferPutter);
		delay(500);
	}
	
	// Start listening for new join requests
	radio.openReadingPipe(1, BASE_PIPE);
	radio.startListening();
}


/**
* Transmit a character to the specified node
*/
void transmitChar(char unitID, char message){
	radio.stopListening();
	radio.openWritingPipe(BASE_PIPE + unitID);
	resetSendBuffer();
	toSendBuffer(message);
	radio.write(sendBuffer, sendBufferPutter);
	radio.startListening();
}


/**
* Check for incoming packets and act accordingly
*/
void checkRadio(){
	if (radio.available()){
		Serial.print("Message received\n");
		//handleIncomingPacket();
	}
}


/**
* Iterate through the routing table and request a sensor data packets
*/
void requestPackets(){
	// Iterate through the routing table and send packet requests
	for(int i = 0; i < routingTablePutter; i++){
		transmitChar(i, DATA_PACKET_REQUEST);
		
		// Wait for response or timeout
		long transmitTime = millis();
		while (!radio.available() && (millis() - transmitTime) < PACKET_REQUEST_TIMEOUT){
			delay(10);
		}
		
		radio.read(receiveBuffer, RECEIVE_BUFFER_SIZE);
		processReceivedPacket();
	}
}


/**
* Send a network join confirmation to the specified unit
*/
void confirmNetworkJoin(char unitID){
	transmitChar(unitID, NETWORK_JOIN_NOTIFIER);
}


/**
* Process a network join request
* Add the node to the routing table if it doesn't already exist
* Also send a join confirmation to stop the node from spamming
*/
void processNetworkJoin(char unitID){
	if(findRoutingEntry(unitID) == ENTRY_NOT_FOUND){
		addRoutingTableEntry(unitID);
	}
	
	confirmNetworkJoin(unitID);
}


/**
* Read and process incoming packets from the RF24 radio
*/
void handleIncomingPacket(){
	resetReceiveBuffer();
	resetSendBuffer();
	radio.read(receiveBuffer, RECEIVE_BUFFER_SIZE);
	processReceivedPacket();
}
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

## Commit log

2014-07-14 Initial Push
    - Lurker Node code is complete but untested
    - Lurker Coordinator code needs some work
    - Lurker Base is completely blank
    [LurkerNanov10.brd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]
2014-07-30 Not sure
    + Filled in some coordinator code
    [LurkerNanov10.brd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]
2014-11-05 Added office lurker variant
    [LurkerNanov10.brd, LurkerNanov10.sch, LurkerNanov11.brd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]
2014-11-14 Output of Office Lurker changed to JSON
    Office lurker now uses all the correct sensors
    Data is transmitted into an easily ingestible format.
    [OfficeLurker_conflict-20141111-160609.ino]
2015-01-15 Big update
    No idea what changes have been made because I've been spoiled by
    IntelliJ, and AtmelStudio is terrible in comparison...
    + Fixed LurkerNano
    - Still need to add in coordinator functions and networking
    - Serial output and control works
    [LurkerCoordinator.ino, LurkerNano.ino, OfficeLurker.ino]
2015-01-25 Save point - About to change to Command libraries
    - About to use command libraries for serial and RF24 command handling
    + Added in 3D printed case files
    [LurkerCase-v3.skp, LurkerCase-v3.stl, LurkerCase.skp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]
2019-03-03 Old updates
    [LurkerNanov10.brd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]

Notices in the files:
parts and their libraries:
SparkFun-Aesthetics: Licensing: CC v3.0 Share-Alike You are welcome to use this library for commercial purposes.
